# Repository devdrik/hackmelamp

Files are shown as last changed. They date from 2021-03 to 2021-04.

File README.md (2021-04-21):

# HackMeLamp

This is HackMeLamp. It is a fun hackable lamp. 
It has 16 RGB LEDs, an ESP8266 µC and an MPU6050 acceleration sensor.

## State of HackMeLamp

HackMeLamp has reached a working state! The PCB works (though I have not yet tested the latest version, but I am using a Version with the same fixes). The code still needs refactoring and features, but it can be used.

HackMeLamp is meant to be a nice lamp that you can use as a backlight for lithophanes. But you can use its motion sensor to activate WiFi. Once you logged into that WiFi you can use the REST API to configure the lamp.
You can find more information on the [blog post](https://devdrik.de/hackmelamp/). 

Feel free to add features or refactor the code.

Also I am very happy for input if you spot bad practices

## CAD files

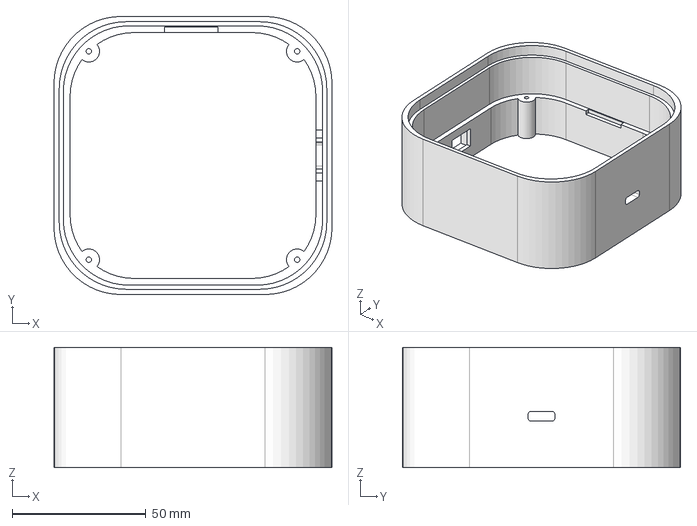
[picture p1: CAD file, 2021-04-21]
cad/hackmelamp_case.step
104.0 x 104.0 x 45.0 mm

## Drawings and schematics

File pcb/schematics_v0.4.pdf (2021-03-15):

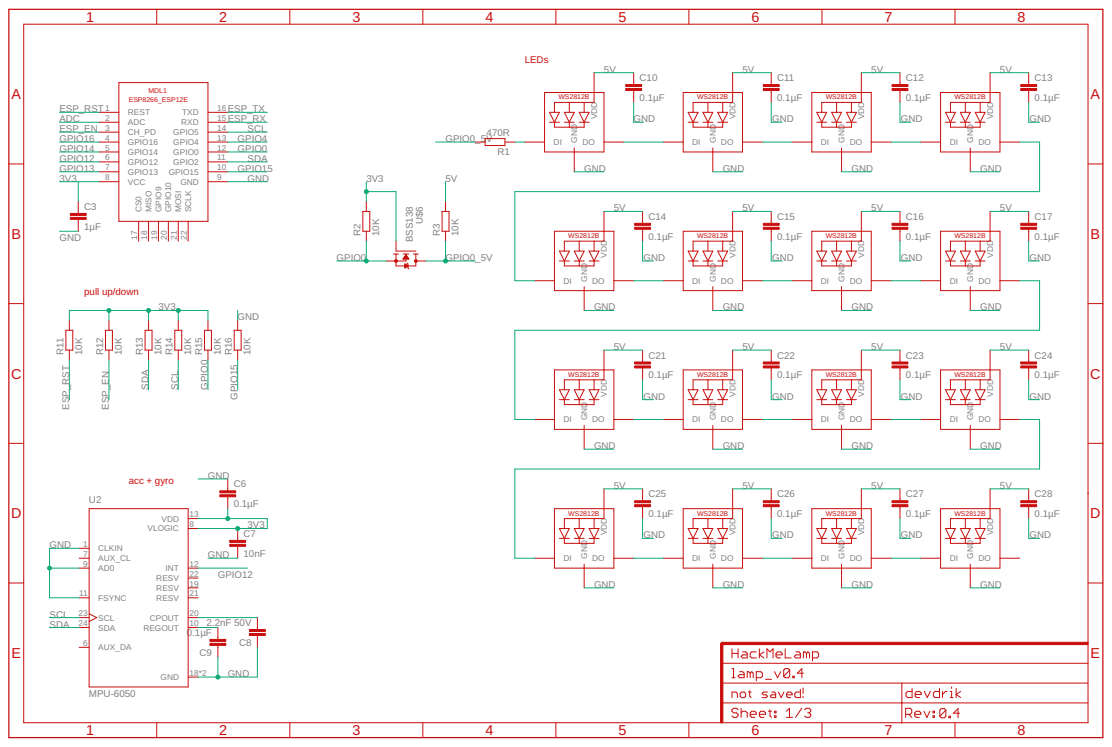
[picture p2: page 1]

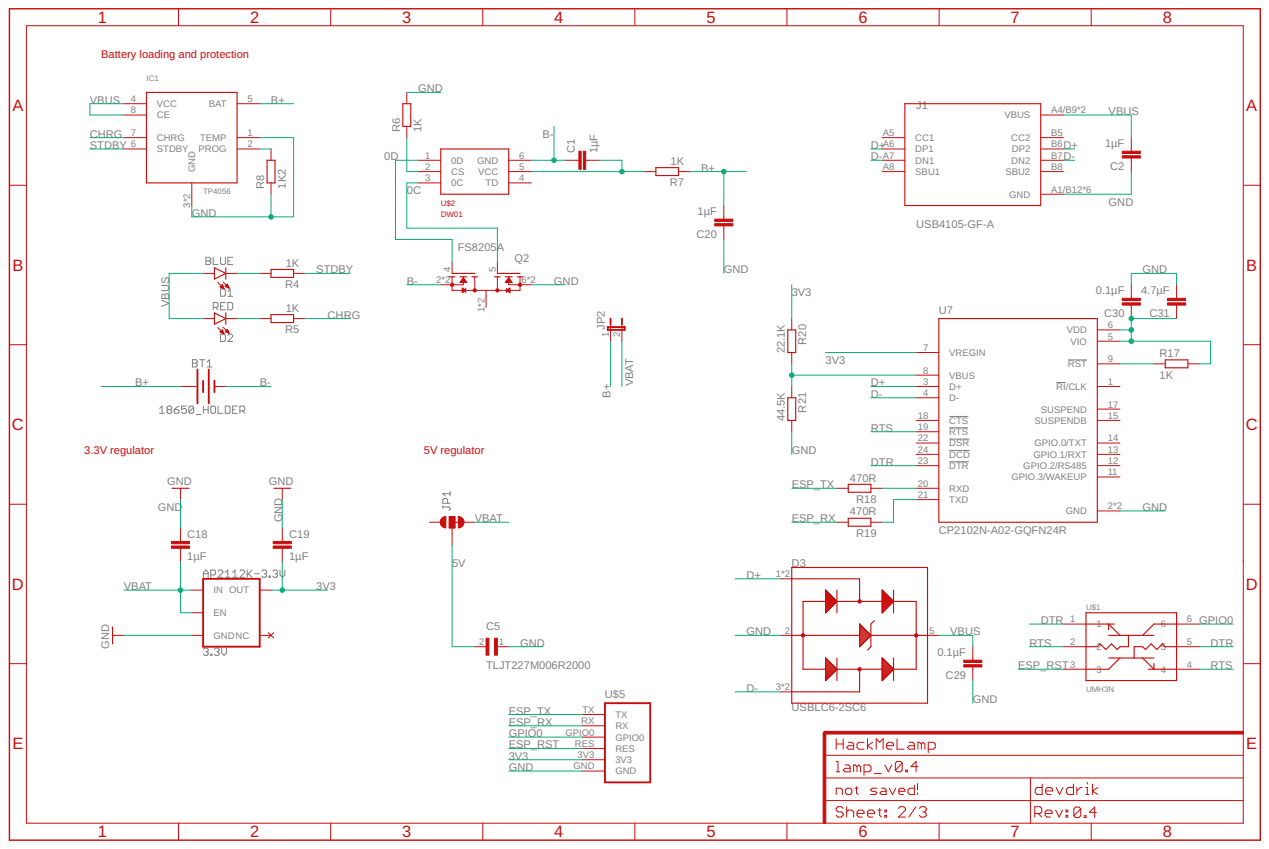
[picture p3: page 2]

Battery loading and protection

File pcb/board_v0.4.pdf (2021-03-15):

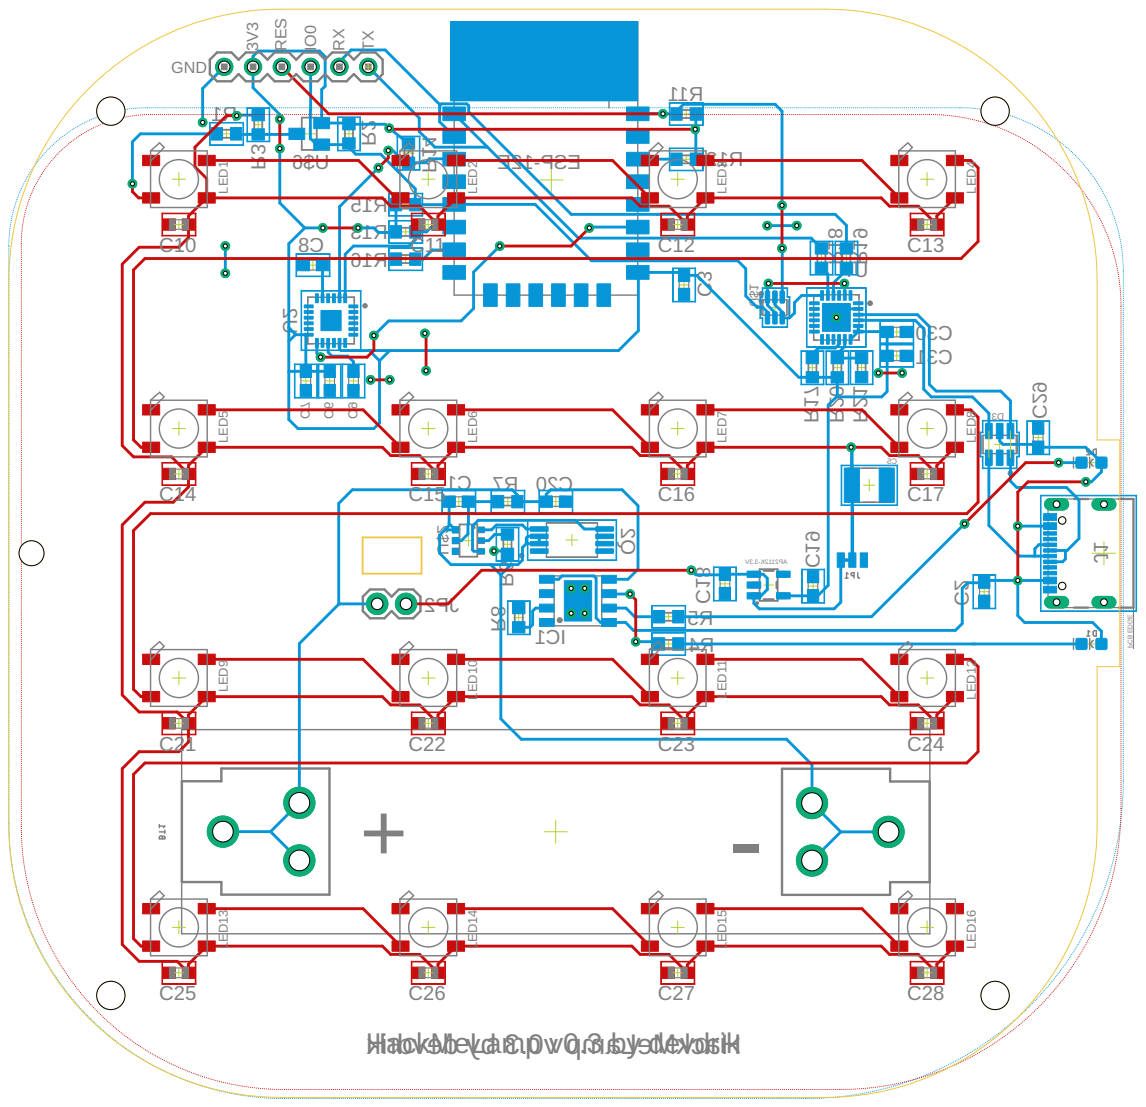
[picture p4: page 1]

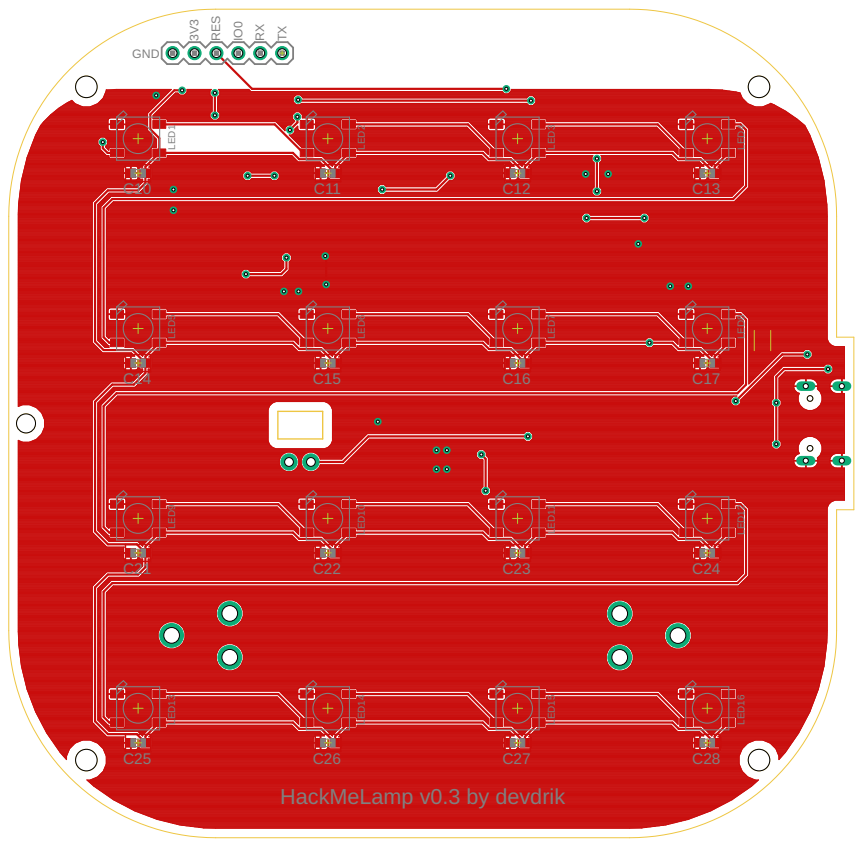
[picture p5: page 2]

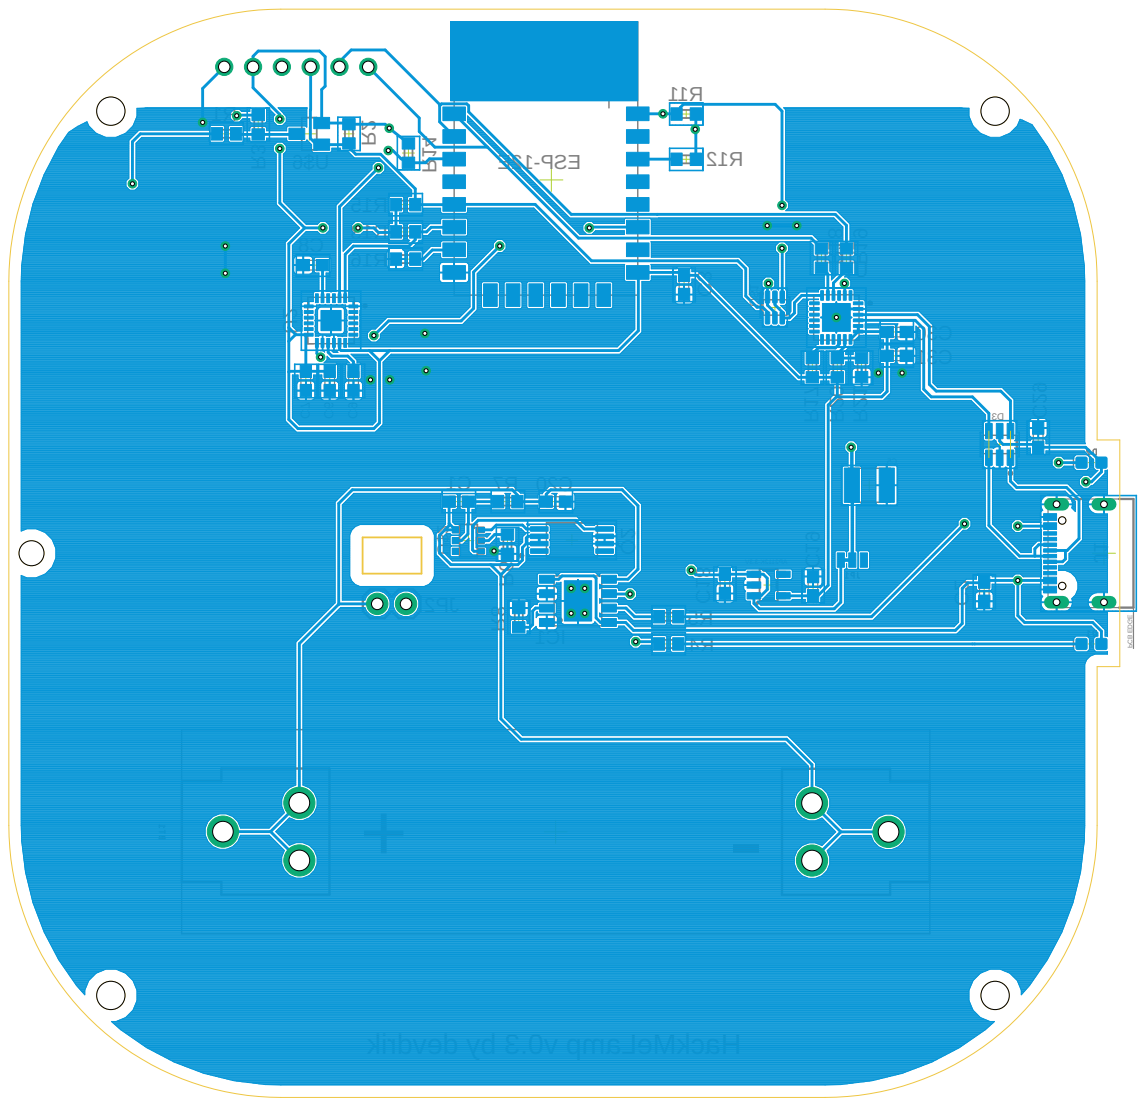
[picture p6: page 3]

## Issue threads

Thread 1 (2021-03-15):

MPU-6050 not working

devdrik, 2021-03-15:
The MPU-6050 IC is not working properly. I can actually sometimes establish a connection to it using the [MPU6050 lib by jrowberg](https://github.com/jrowberg/i2cdevlib/tree/master/Arduino/MPU6050). But I only receive 0's. Most of the time the connection just fails.
If you can spot any errors on the board, please let me know.

1randy, 2021-03-16:
according to the schematics, R13/R14 (i2c pullups) are 10k; in 3V3 systems, those should be 4k7 or even lower (3k3/2k7).
thank could explain the connection issues.

devdrik, 2021-03-16:
Thanks. I swapped them, but it did not fix it.

The problem was that I got a bad batch of MPU6050 ICs. I tested 7 of them on 3 different PCBs. None of them worked. Then I tried one from a different batch and it worked immediately...

Closed 2021-03-16.

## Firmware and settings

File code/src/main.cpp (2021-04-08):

#include <Arduino.h>


#include <ESP8266WiFi.h>
#include <ESPAsyncTCP.h>
#include <ESPAsyncWebServer.h>
#include <ArduinoOTA.h>

#include <ESP8266mDNS.h>

// #include <MotionSensor.h>
#include <LEDs.h>
// #include "myTypes.h"
#include <Persistor.h>

#include "colorpicker_html.h"
#include "index_html.h"



/************************************************************
 * *                                                      * *
 * *        Start OF MOTION SENSOR CLASS HEADER           * *
 * *                                                      * *
 * *********************************************************/

/* This should live in its own file, but I do not get it to work then 🤷 */

#include <Wire.h>
#include "MPU6050_6Axis_MotionApps20.h"
#ifndef M_PI
    #define M_PI 3.14159265358979323846
#endif
class MotionSensor
{
public:
    MotionSensor();
    void init();
    void updateGyroData();
    void updateAccData();
    void meanaccelgyro();
    void calibaccelgyro();

    bool zAccExceededLimit(long limit);
    bool xyAccExceededLimit(long limit);

    bool isAccLimitReached();
    bool isUpsideDown();

    void setAZLimit(int);
    int getAZLimit();

    void setShockLimit(long);

    int getAX();
    int getAY();
    int getAZ();
    int getGX();
    int getGY();
    int getGZ();

private:
    bool USESERIAL = false;
    MPU6050 mpu;
    // MPU control/status vars
    /*unntig?*/ bool dmpReady = false;  // set true if DMP init was successful
    uint8_t devStatus;      // return status after each device operation (0 = success, !0 = error)
    uint16_t packetSize;    // expected DMP packet size (default is 42 bytes)
    uint16_t fifoCount;     // count of all bytes currently in FIFO
    uint8_t fifoBuffer[64]; // FIFO storage buffer

    // orientation/motion vars
    Quaternion q;           // [w, x, y, z]         quaternion container
    VectorInt16 aa;         // [x, y, z]            accel sensor measurements
    VectorInt16 aaReal;     // [x, y, z]            gravity-free accel sensor measurements
    VectorInt16 aaWorld;    // [x, y, z]            world-frame accel sensor measurements
    VectorFloat gravity;    // [x, y, z]            gravity vector
    float ypr[3];           // [yaw, pitch, roll]   yaw/pitch/roll container and gravity vector
    float yprd[3];           //ypr in degree
    float xyz[3];
    float yaw;
    float initYaw = 0;  //Initial Yaw after sense call
    int16_t ax, ay, az, gx, gy, gz;
    long ax_buff, ay_buff, az_buff, gx_buff, gy_buff, gz_buff;

    long shockLimit = 21000;
    bool issensed = false;

    int azLimit = -14000;
};

/************************************************************
 * *                                                      * *
 * *        END OF MOTION SENSOR CLASS HEADERS            * *
 * *                                                      * *
 * *********************************************************/

MotionSensor motion;
LEDs leds;
Persistor persistor;

AsyncWebServer asyncServer(80);

//I2C (MPU6050)
#define SCL 5
#define SDA 2

bool USESERIAL = true;
bool useSerial = USESERIAL;

bool updateCheckStartet = false;
unsigned long updateStartTime;
unsigned long durationToStartWiFi = 7000;

bool isUpdateMode = false;
bool wifiOff = true;

void startUpdateMode() {
  leds.setColor(0,0,255);
  leds.on();
  asyncServer.end();
  WiFiServer server(5005);
  server.begin();

  isUpdateMode = true;
  delay(10);

  ArduinoOTA.onStart([]() {
    if (useSerial)
    {
      Serial.println("Start");
    }
  });
  ArduinoOTA.onEnd([]() {
    WiFi.mode(WIFI_OFF); //turn off wifi
    if (useSerial)
    {
      Serial.println("\nEnd");
    }
    ESP.restart();
  });
  ArduinoOTA.onProgress([](unsigned int progress, unsigned int total) {
    if (useSerial)
    {
      Serial.printf("Progress: %u%%\r", (progress / (total / 100)));
    }
  });
  ArduinoOTA.onError([](ota_error_t error) {
    if (useSerial)
    {
      Serial.printf("Error[%u]: ", error);
    }
    if (error == OTA_AUTH_ERROR && useSerial)
      Serial.println("Auth Failed");
    else if (error == OTA_BEGIN_ERROR && useSerial)
      Serial.println("Begin Failed");
    else if (error == OTA_CONNECT_ERROR && useSerial)
      Serial.println("Connect Failed");
    else if (error == OTA_RECEIVE_ERROR && useSerial)
      Serial.println("Receive Failed");
    else if (error == OTA_END_ERROR && useSerial)
      Serial.println("End Failed");
    WiFi.mode(WIFI_OFF); //turn off wifi
    ESP.restart();
  });
  ArduinoOTA.begin();
}

const char *PARAM_R = "r";
const char *PARAM_G = "g";
const char *PARAM_B = "b";
const char *PARAM_ID = "id";
const char *PARAM_SSID = "ssid";
const char *PARAM_PASSWORD = "password";
const char *PARAM_SHOCK_LIMIT = "limit";
const char *PARAM_BLINK_DURATION = "duration";
const char *PARAM_COLOR = "color";
const char *PARAM_MODE = "mode";

void createAPI() {
  asyncServer.on("/", HTTP_GET, [](AsyncWebServerRequest *request) {
    request->send_P(200, "text/html", index_html);
  });

  asyncServer.on("/colors", HTTP_GET, [](AsyncWebServerRequest *request) {
    request->send_P(200, "text/html", colors_html);
  });

  asyncServer.on("/on", HTTP_GET, [](AsyncWebServerRequest *request) {
    leds.on();
    request->send_P(200, "text/html", "its on");
  });

  asyncServer.on("/off", HTTP_GET, [](AsyncWebServerRequest *request) {
    leds.off();
    request->send_P(200, "text/html", "its off");
  });

  asyncServer.on("/rgball", HTTP_GET, [](AsyncWebServerRequest *request) {
    if (request->hasParam(PARAM_R) && request->hasParam(PARAM_G) && request->hasParam(PARAM_B))
    {
      int r = request->getParam(PARAM_R)->value().toInt();
      int g = request->getParam(PARAM_G)->value().toInt();
      int b = request->getParam(PARAM_B)->value().toInt();
      if (leds.isRGBInvalid(r, g, b)) {
        request->send(400, "text/plain", "invalid value");
      } else {
        leds.setColor(r,g,b);
        leds.on();
        request->send_P(200, "text/html", "color changed");
      }
    } else {
      request->send(400, "text/plain", "missing parameters");
    }
  });

  asyncServer.on("/rgbsingle", HTTP_GET, [](AsyncWebServerRequest *request) {
    if (request->hasParam(PARAM_ID) && request->hasParam(PARAM_R) && request->hasParam(PARAM_G) && request->hasParam(PARAM_B))
    {
      int r = request->getParam(PARAM_R)->value().toInt();
      int g = request->getParam(PARAM_G)->value().toInt();
      int b = request->getParam(PARAM_B)->value().toInt();
      int id = request->getParam(PARAM_ID)->value().toInt();
      if (leds.isRGBInvalid(r, g, b) || !leds.isIdValid(id)) {
        request->send(400, "text/plain", "invalid value");
      } else {
        leds.changeSingleColor(id, r, g, b);
        request->send_P(200, "text/html", "color changed");
      }
    } else {
      request->send(400, "text/plain", "missing parameters");
    }
  });

  asyncServer.on("/startupdate", HTTP_GET, [](AsyncWebServerRequest *request) {
    request->send_P(200, "text/html", "starting update mode...on port 5005...I am an ESP8266..");
    startUpdateMode();
  });

  asyncServer.on("/setcredentials", HTTP_GET, [](AsyncWebServerRequest *request) {
    if (request->hasParam(PARAM_SSID) && request->hasParam(PARAM_PASSWORD))
    {
      String newSSID = request->getParam(PARAM_SSID)->value();
      String newPassword = request->getParam(PARAM_PASSWORD)->value();
      if (newSSID.length() > 32 || newPassword.length() > 32) {
        request->send(400, "text/plain", "max length of SSID and Password is 32 characters");
      } else if (newSSID.length() < 1 || newPassword.length() < 1) {
        request->send(400, "text/plain", "min length of SSID and Password is 1 character");
      } else {
        persistor.setCredentials(newSSID, newPassword);
        request->send_P(200, "text/html", "New credentials set. They are effective after next reboot. Don't forget to turn on Wifi again..");
      }
    } else {
      request->send(400, "text/plain", "missing parameters");
    }
  });

  asyncServer.on("/changeshocklimit", HTTP_GET, [](AsyncWebServerRequest *request) {
    if (request->hasParam(PARAM_SHOCK_LIMIT))
    {
      long newLimit = request->getParam(PARAM_SHOCK_LIMIT)->value().toInt();
      if (newLimit > 32000 || newLimit < 0) {
        request->send(400, "text/plain", "invalid limit value");
      } else {
        persistor.config.shockLimit = newLimit;
        request->send_P(200, "text/html", "limit changed");
      }
    } else {
      request->send(400, "text/plain", "missing parameters");
    }
  });

  asyncServer.on("/changeblinkduration", HTTP_GET, [](AsyncWebServerRequest *request) {
    if (request->hasParam(PARAM_BLINK_DURATION))
    {
      long newDuration = request->getParam(PARAM_BLINK_DURATION)->value().toInt();
      if (newDuration <= 0) {
        request->send(400, "text/plain", "invalid duration");
      } else {
        persistor.config.blinkDuration = newDuration;
        request->send_P(200, "text/html", "duration changed");
      }
    } else {
      request->send(400, "text/plain", "missing parameters");
    }
  });

  asyncServer.on("/persist", HTTP_GET, [](AsyncWebServerRequest *request) {
      request->send(203, "text/plain", "your config now lives through a restart");
      persistor.saveConfig();
  });

  asyncServer.on("/singlecolor", HTTP_GET, [](AsyncWebServerRequest *request) {
    if (request->hasParam(PARAM_ID) && request->hasParam(PARAM_COLOR))
    {
      int id = request->getParam(PARAM_ID)->value().toInt();
      uint32_t color = request->getParam(PARAM_COLOR)->value().toInt();
      Serial.print("color: ");
      Serial.println(color);
      if (!leds.isIdValid(id)) {
        request->send(400, "text/plain", "invalid id");
      } else {
        leds.changeSingleColor(id, color);
        request->send_P(200, "text/html", "color changed for single LED");
      }
    } else {
      request->send(400, "text/plain", "missing parameters");
    }
  });

  asyncServer.on("/mode", HTTP_GET, [](AsyncWebServerRequest *request) {
    if (request->hasParam(PARAM_MODE))
    {
      int mode = request->getParam(PARAM_MODE)->value().toInt();
      leds.setMode(mode);
      request->send_P(200, "text/html", "mode test running");
    } else {
      request->send(400, "text/plain", "missing parameters");
    }
  });

  asyncServer.onNotFound([](AsyncWebServerRequest *request){
    request->send(404);
  });
}

void startWiFi() {
  wifiOff = false;
  // leds.setColor(255,0,0);
  // leds.on();
  persistor.loadCredentials();
  WiFi.mode(WIFI_STA);
  WiFi.hostname("hackmelamp");
  WiFi.begin(persistor.credentials.ssid, persistor.credentials.password);
  unsigned long wifiStartupTime = millis();
  unsigned long wifiConnectWaitTime = 10000;
  bool startAp = false;
  while (WiFi.status() != WL_CONNECTED)
  {
    if (millis() > (wifiStartupTime + wifiConnectWaitTime)) {
      if (USESERIAL) {
        Serial.println("Cannot connect, opening AP");
      }
      startAp = true;
      WiFi.disconnect(true);
      break;
    }
    delay(1000);
  }
  if(!startAp && USESERIAL) {
    Serial.print("hostname:");
    Serial.println(WiFi.hostname());
  }

  if(startAp) {
    // IPAddress Ip(192, 168, 4, 111);
    // IPAddress NMask(255, 255, 255, 0);
    WiFi.mode(WIFI_AP);
    // WiFi.softAPConfig(Ip, Ip, NMask);
    WiFi.softAP("LithoLamp", "LithoLamp");

    delay(500);
  }
  createAPI();
  asyncServer.begin();
  // leds.setColor(0,255,0),
  // leds.on();
}

void checkWiFiStartRoutine() {
  if (wifiOff) {
    // if (motion.isUpsideDown() && !updateCheckStartet) {
    //   updateStartTime = millis();
    //   updateCheckStartet = true;
    // } else if (motion.isUpsideDown() && updateCheckStartet) {
    //   if (millis() > updateStartTime + durationToStartWiFi) {
    //     startWiFi();
    //   }
    // } else if (updateCheckStartet && !motion.isUpsideDown()) {
    //   updateCheckStartet = false;
    // }
  }
}

void setup() {
  Serial.begin(115200);

  // start I2C for MPU6050
  Wire.begin(SDA, SCL);
  Wire.setClock(400000);
  
  WiFi.mode(WIFI_OFF);

  persistor.loadConfig();


  leds.init();
  leds.service();

  motion.init();
  motion.calibaccelgyro();

  startWiFi();
}

void loop() {
  if ( isUpdateMode ) {
    ArduinoOTA.handle();
  } else {
    // checkWiFiStartRoutine();
    if (motion.zAccExceededLimit(persistor.config.shockLimit)) {
      // leds.blinkFancy(persistor.config.blinkDuration);
      leds.colorEasterEggBunny();
    } else if (motion.xyAccExceededLimit(persistor.config.shockLimit)) {
      leds.testMode2();
    }
  }
  leds.service();
}






/************************************************************
 * *                                                      * *
 * *        Start OF MOTION SENSOR CLASS IMPLEMENTATION   * *
 * *                                                      * *
 * *********************************************************/

/* This should live in its own file, but I do not get it to work then 🤷 */

MotionSensor::MotionSensor() {}

void MotionSensor::init() {
    // Init Gyro

  // initialize device
  if(USESERIAL){
    Serial.println(F("Initializing I2C devices..."));
  }
  mpu.initialize();
  //pinMode(INTERRUPT_PIN, INPUT);

  // verify connection
  if(USESERIAL){
    Serial.println(F("Testing device connections..."));
    Serial.println(mpu.testConnection() ? F("MPU6050 connection successful") : F("MPU6050 connection failed"));
  }

  // load and configure the DMP
  if(USESERIAL){
    Serial.println(F("Initializing DMP..."));
  }
  devStatus = mpu.dmpInitialize();
  // make sure it worked (returns 0 if so)
  if (devStatus == 0) {
    // turn on the DMP, now that it's ready
    if(USESERIAL){
      Serial.println(F("Enabling DMP..."));
    }
    mpu.setDMPEnabled(true);

    // set our DMP Ready flag so the main loop() function knows it's okay to use it
    if(USESERIAL){
      Serial.println(F("DMP ready! Waiting for first interrupt..."));
    }
    dmpReady = true;

    // get expected DMP packet size for later comparison
    packetSize = mpu.dmpGetFIFOPacketSize();
  } else {
    // ERROR!
    // 1 = initial memory load failed
    // 2 = DMP configuration updates failed
    // (if it's going to break, usually the code will be 1)
    if(USESERIAL){
      Serial.print(F("DMP Initialization failed (code "));
      Serial.print(devStatus);
      Serial.println(F(")"));
    }
  }
}

void MotionSensor::updateGyroData() {
  mpu.resetFIFO();
  fifoCount = 0;
  // wait for correct available data length, should be a VERY short wait
  while (fifoCount < packetSize) {
    fifoCount = mpu.getFIFOCount();
    //Serial.println("hanging in FIFO count..");
  }

  // read a packet from FIFO
  mpu.getFIFOBytes(fifoBuffer, packetSize);

  mpu.dmpGetQuaternion(&q, fifoBuffer);
  mpu.dmpGetGravity(&gravity, &q);
  mpu.dmpGetYawPitchRoll(ypr, &q, &gravity);
  yprd[0] = ypr[0] * 180 / M_PI + 180;
  yprd[1] = ypr[1] * 180 / M_PI;
  yprd[2] = ypr[2] * 180 / M_PI;
  /*Serial.print("ypr\t");
    Serial.print(yprd[0]);
    Serial.print("\t");
    Serial.print(yprd[1]);
    Serial.print("\t");
    Serial.println(yprd[2]);*/
}

void MotionSensor::updateAccData() {
  mpu.getAcceleration(&ax, &ay, &az);
  if(USESERIAL){
    Serial.print("ax, ay, az:\t");
    Serial.print(ax);
    Serial.print("\t");
    Serial.print(ay);
    Serial.print("\t");
    Serial.println(az);
  }
}

int mean_ax, mean_ay, mean_az, mean_gx, mean_gy, mean_gz;

void MotionSensor::meanaccelgyro() {
  long i = 0, buff_ax = 0, buff_ay = 0, buff_az = 0, buff_gx = 0, buff_gy = 0, buff_gz = 0;
  int agmeanbuffer = 50;   //Amount of readings used to average, make it higher to get more precision but sketch will be slower  (default:1000)
  int disg = 30;

  while (i < (agmeanbuffer + disg + 1)) {
    // read raw accel/gyro measurements from device
    mpu.getMotion6(&ax, &ay, &az, &gx, &gy, &gz);

    if (i > disg && i <= (agmeanbuffer + disg)) { //First disg measures are discarded
      buff_ax = buff_ax + ax;
      buff_ay = buff_ay + ay;
      buff_az = buff_az + az;
      buff_gx = buff_gx + gx;
      buff_gy = buff_gy + gy;
      buff_gz = buff_gz + gz;
    }
    if (i == (agmeanbuffer + disg)) {
      mean_ax = buff_ax / agmeanbuffer;
      mean_ay = buff_ay / agmeanbuffer;
      mean_az = buff_az / agmeanbuffer;
      mean_gx = buff_gx / agmeanbuffer;
      mean_gy = buff_gy / agmeanbuffer;
      mean_gz = buff_gz / agmeanbuffer;
    }
    i++;
    delay(1); //Needed so we don't get repeated measures
  }
}



void MotionSensor::calibaccelgyro() {
  int ax_offset, ay_offset, az_offset, gx_offset, gy_offset, gz_offset;
  int giro_deadzone = 3;   //Giro error allowed, make it lower to get more precision, but sketch may not converge  (default:1)
  int acel_deadzone = 20;   //Acelerometer error allowed, make it lower to get more precision, but sketch may not converge  (default:8)
  mpu.setXAccelOffset(0);
  mpu.setYAccelOffset(0);
  mpu.setZAccelOffset(0);
  mpu.setXGyroOffset(0);
  mpu.setYGyroOffset(0);
  mpu.setZGyroOffset(0);

  meanaccelgyro();

  ax_offset = -mean_ax / 8;
  ay_offset = -mean_ay / 8;
  az_offset = - mean_az / 8;

  gx_offset = -mean_gx / 4;
  gy_offset = -mean_gy / 4;
  gz_offset = -mean_gz / 4;
  int agready = 0;
  int agcount = 0;
  while (agready < 6 && agcount < 11) {
    agready = 0;
    agcount++;
    mpu.setXAccelOffset(ax_offset);
    mpu.setYAccelOffset(ay_offset);
    mpu.setZAccelOffset(az_offset);

    mpu.setXGyroOffset(gx_offset);
    mpu.setYGyroOffset(gy_offset);
    mpu.setZGyroOffset(gz_offset);

    meanaccelgyro();

    if (abs(mean_ax) <= acel_deadzone) agready++;
    else ax_offset = ax_offset - mean_ax / acel_deadzone;

    if (abs(mean_ay) <= acel_deadzone) agready++;
    else ay_offset = ay_offset - mean_ay / acel_deadzone;

    if (abs(mean_az) <= acel_deadzone) agready++;
    else az_offset = az_offset  - mean_az / acel_deadzone;

    if (abs(mean_gx) <= giro_deadzone) agready++;
    else gx_offset = gx_offset - mean_gx / (giro_deadzone + 1);

    if (abs(mean_gy) <= giro_deadzone) agready++;
    else gy_offset = gy_offset - mean_gy / (giro_deadzone + 1);

    if (abs(mean_gz) <= giro_deadzone) agready++;
    else gz_offset = gz_offset - mean_gz / (giro_deadzone + 1);

    if(USESERIAL){
      Serial.print(".");
    }
  }
  if(USESERIAL){
    Serial.print("\nSensor readings with offsets:\t");
    Serial.print(mean_ax);
    Serial.print("\t");
    Serial.print(mean_ay);
    Serial.print("\t");
    Serial.print(mean_az);
    Serial.print("\t");
    Serial.print(mean_gx);
    Serial.print("\t");
    Serial.print(mean_gy);
    Serial.print("\t");
    Serial.println(mean_gz);
    Serial.print("Your offsets:\t");
    Serial.print(ax_offset);
    Serial.print("\t");
    Serial.print(ay_offset);
    Serial.print("\t");
    Serial.print(az_offset);
    Serial.print("\t");
    Serial.print(gx_offset);
    Serial.print("\t");
    Serial.print(gy_offset);
    Serial.print("\t");
    Serial.println(gz_offset);
  }
}

bool MotionSensor::isAccLimitReached() {
    updateAccData();
    return abs(ax) > shockLimit || abs(ay) > shockLimit || abs(az) > shockLimit;
}

bool MotionSensor::isUpsideDown() {
    updateAccData();
    return az < azLimit;
}

int MotionSensor::getAZLimit() {
    return azLimit;
}

void MotionSensor::setAZLimit(int newLimit) {
    azLimit = newLimit;
}

void MotionSensor::setShockLimit(long newLimit) {
  shockLimit = newLimit;
}

int MotionSensor::getAX(){
    // mpu.getMotion6(&ax, &ay, &az, &gx, &gy, &gz);
    return ax;
};
int MotionSensor::getAY(){
    // mpu.getMotion6(&ax, &ay, &az, &gx, &gy, &gz);
    return ay;
};
int MotionSensor::getAZ(){
    // mpu.getMotion6(&ax, &ay, &az, &gx, &gy, &gz);
    return az;
};
int MotionSensor::getGX(){
    // mpu.getMotion6(&ax, &ay, &az, &gx, &gy, &gz);
    return gx;
};
int MotionSensor::getGY(){
    // mpu.getMotion6(&ax, &ay, &az, &gx, &gy, &gz);
    return gy;
};
int MotionSensor::getGZ(){
    // mpu.getMotion6(&ax, &ay, &az, &gx, &gy, &gz);
    return gz;
};

bool MotionSensor::zAccExceededLimit(long limit) {
  updateAccData();
  return abs(az) > limit;
}

bool MotionSensor::xyAccExceededLimit(long limit) {
  updateAccData();
  return abs(ax) > limit || abs(ay) > limit;
}

/************************************************************
 * *                                                      * *
 * *        END OF MOTION SENSOR CLASS IMPLEMENTATION     * *
 * *                                                      * *
 * *********************************************************/

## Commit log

2021-04-08 added pcb folder
2021-04-08 added arduino code (work in progress)
2021-04-21 added case stp file
    [hackmelamp_case.step]
2021-04-21 added gerber files
    [lamp_v0.4.GBL, lamp_v0.4.GBO, lamp_v0.4.GBP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]
